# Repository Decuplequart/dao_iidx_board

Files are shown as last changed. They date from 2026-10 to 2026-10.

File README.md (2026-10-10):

# DAO Controller Board

DAO系IIDXコントローラーの既存ボタン、ターンテーブルセンサー、LEDハーネスを再利用し、USB HIDおよびBluetooth Low Energy HIDへの対応を目指す交換用コントローラー基板です。

本リポジトリには、KiCadで作成した回路図・PCBデータ、プロジェクト固有ライブラリ、およびJLCPCB向け製造データ生成に必要な設定を収録します。

Repository: https://github.com/Decuplequart/dao_iidx_board

> [!WARNING]
> この基板は現在 **Rev.1の試作段階** です。実機での完全な動作確認、長時間運転、全LED同時点灯時の温度評価、USB/BLEファームウェア検証は完了していません。製造・実装・使用は自己責任で行ってください。

## 主な機能

- 7鍵入力
- START / SELECT入力
- 2相ターンテーブルセンサー入力（RD1 / RD2）
- USB 2.0 Full-Speed HID対応を想定
- Bluetooth Low Energy HID対応を想定
- DAO系単色ボタンLED 9系統の個別制御
- RESETボタン
- MODE / PAIRボタン
- SWD書き込み端子
- 8 GPIOの拡張端子
- USB Type-C給電
- モバイルバッテリー給電によるBLE運用を想定

## 設計方針

この基板は内蔵バッテリーを搭載せず、USB Type-Cからの5V給電に統一しています。

- 有線使用時: PCとのUSB通信および給電
- 無線使用時: BLE通信および外部モバイルバッテリーからの給電

内蔵LiPo、充電回路、昇圧回路を省略することで、回路の簡略化、安全性の向上、保守性の改善を狙っています。

## ハードウェア構成

### マイコン

- Raytac `MDBT50Q-1MV2`
- Nordic Semiconductor `nRF52840`搭載
- USB / BLE対応
- チップアンテナ内蔵
- SWD経由で初回書き込み可能

JLCPCB/LCSC部品番号:

```text
C5118826
```

この部品は通常在庫ではなく、事前注文が必要になる場合があります。また、ブートローダーやアプリケーションが未書き込みの可能性があるため、SWD書き込みを前提としてください。

### LEDドライバ

- Texas Instruments `TLC6C598PWR` × 2
- 8ch DMOSオープンドレイン出力
- 2個をカスケード接続し、9系統を使用

DAO系単色ボタンLEDの実測電流は1灯あたり約40～50mAでした。LED電源は5V、ドライバ出力はローサイドシンク方式です。

```text
U2 DRAIN0～7 -> LED_K1～LED_K8
U3 DRAIN0    -> LED_K9
```

### 電源

```text
USB Type-C VBUS
  -> VBUS_5V
     -> MDBT50Q VDDH / VBUS
     -> TLC6C598 × 2
     -> KEY_LED_5V
     -> SCR_5V
     -> DISH_LED_5V
```

- 内蔵バッテリーなし
- USB Type-C受電用CC抵抗: 5.1kΩ × 2
- キーLED共通電源は太配線で分配
- 裏面GNDゾーンを使用

## GPIO割り当て

| 機能 | nRF52840 GPIO |
|---|---|
| K1 | P0.02 |
| K2 | P0.03 |
| K3 | P0.04 |
| K4 | P0.05 |
| K5 | P0.28 |
| K6 | P0.29 |
| K7 | P0.30 |
| START | P0.00 |
| SELECT | P0.01 |
| MODE_PAIR | P0.06 |
| RD1 | P0.13 |
| RD2 | P0.14 |
| LED_DATA | P0.15 |
| LED_CLK | P0.16 |
| LED_LATCH | P0.17 |
| RESET | P0.18 / nRESET |

### 拡張GPIO

`GPIO_EXPANSION`端子へ次の8本を引き出しています。

```text
EXP0 -> P0.19
EXP1 -> P0.20
EXP2 -> P0.21
EXP3 -> P0.22
EXP4 -> P0.23
EXP5 -> P0.24
EXP6 -> P0.25
EXP7 -> P0.26
```

将来のPS2対応や追加I/Oへの利用を想定していますが、現時点では用途・ファームウェアとも未確定です。

## コネクター

| 機能 | 種類 |
|---|---|
| DISH_LED | JST XH 2極、2.50mm、垂直 |
| KEY1～KEY7 | JST XH 4極、2.50mm、垂直 |
| START / SELECT | JST XH 4極、2.50mm、垂直 |
| DISH_SENSOR | JST XH 4極、2.50mm、垂直 |
| SWD | 1×4、2.54mmピンヘッダー |
| GPIO_EXPANSION | 2×5、2.54mmピンヘッダー |

キー・START・SELECT用4極コネクターの基本構成:

```text
Pin 1: スイッチ入力
Pin 2: LED制御端子（LOWで点灯）
Pin 3: KEY_LED_5V
Pin 4: GND
```

実際の既存ハーネスを接続する前に、必ず導通とピン順を確認してください。

## SWD端子

```text
J3 Pin 1: +3V3 / VTref
J3 Pin 2: SWDIO
J3 Pin 3: SWDCLK
J3 Pin 4: GND
```

J-Link、nRF52840 DK、またはJLCPCBのプログラミングサービスを使った初回書き込みを想定しています。

## 基板仕様

```text
基板外形: 80.00 mm × 57.00 mm
層数: 2層
推奨板厚: 1.6 mm
銅厚: 1 oz
固定穴: 4個、5.5 mm NPTH
```

固定穴中心位置は、基板左上を `(0, 0)` とした場合、次のとおりです。

```text
左上: ( 4.5, 15.0 ) mm
右上: (75.5, 15.0 ) mm
左下: ( 4.5, 45.0 ) mm
右下: (75.5, 45.0 ) mm
```

## アンテナ領域の注意

`MDBT50Q-1MV2`のアンテナKEEP OUT内には、表裏とも次を配置しないでください。

- 銅箔ゾーン
- 配線
- ビア
- 部品
- 金属スペーサー
- ネジや金属板

Gerber出力後、アンテナ領域からGNDベタが正しく抜けていることを必ず確認してください。

## 主なJLCPCB/LCSC部品

| リファレンス | 部品 | LCSC番号 |
|---|---|---|
| C1, C3, C4, C6 | 100nF / 16V / 0402 | C1525 |
| C2, C5 | 4.7uF / 16V / 0603 | C19666 |
| D1 | 1SS404 / SOD-323 | C2847422 |
| D2 | SS14 / SMA | C2480 |
| R1 | 0Ω / 0402 | C17168 |
| R2, R3 | 5.1kΩ / 0402 | C25905 |
| R4, R5 | 10kΩ / 0402 | C25744 |
| R6, R7 | 1kΩ / 0402 | C11702 |
| SW1, SW2 | SMDタクトスイッチ | C49234124 |
| U1 | MDBT50Q-1MV2 | C5118826 |
| U2, U3 | TLC6C598PWR | C2863406 |
| USB-C | TYPE-C-31-M-12 | C165948 |
| J1 | JST B2B-XH-A | C158012 |
| J3 | 1×4 2.54mmピンヘッダー | C5116483 |
| J4 | 2×5 2.54mmピンヘッダー | C492422 |
| J5～J14 | JST B4B-XH-A | C144395 |

> [!NOTE]
> 在庫、価格、Basic/Extended区分、Standard PCBA対応状況は変動します。発注直前にJLCPCBの部品ページと実装プレビューで再確認してください。

## リポジトリ構成

```text
.
├─ *.kicad_pro              KiCadプロジェクト
├─ *.kicad_sch              回路図
├─ *.kicad_pcb              PCB
├─ *.kicad_sym              プロジェクト固有シンボル
├─ *.pretty/                プロジェクト固有フットプリント
├─ *.3dshapes/              3Dモデル
├─ fp-lib-table             フットプリントライブラリ設定
├─ sym-lib-table            シンボルライブラリ設定
└─ README.md
```

3Dモデルは製造そのものには必須ではありません。Gerber、ドリル、BOM、CPLの内容を優先してください。

## 製造データの生成

KiCad用`JLCPCB Tools`プラグインを使用する場合:

1. PCBエディターでDRCを実行
2. エラー0、未配線0を確認
3. GNDゾーンを再計算
4. JLCPCB Toolsを開く
5. 各実装部品へLCSC番号を割り当て
6. 固定穴とテストポイントをBOM/POSから除外
7. `Generate`を実行

PCBA発注に必要な主なファイル:

```text
Gerber + Drill ZIP
BOM.csv
CPL / Positions.csv
```

発注時はJLCPCBのプレビューで、少なくとも次を確認してください。

- U1、U2、U3の1番ピン方向
- D1、D2のカソード方向
- USB Type-Cの向き
- JST-XHコネクターの向き
- タクトスイッチの位置
- SMT部品の回転角
- PTH/NPTH穴
- アンテナKEEP OUT
- 表裏シルク

## ファームウェア

ファームウェアは別途開発予定です。

想定機能:

- USB HIDゲームコントローラー
- BLE HIDゲームコントローラー
- 7鍵、START、SELECT入力
- ターンテーブル2相入力
- LED制御
- MODE / PAIR操作
- 将来の拡張GPIO利用

初回書き込みはSWDを使用します。JLCPCBへ書き込みを依頼する場合は、対象デバイス、SWD端子定義、書き込み対象HEX、Erase/Program/Verify手順を明記してください。

## 既知の注意事項

- Rev.1は未検証です。
- DAO系コントローラーの世代やモデルにより、ハーネスのピン配列が異なる可能性があります。
- LED電流は実機で約40～50mA/灯を観測しています。
- 9灯同時点灯時はLEDだけで約360～450mAになる可能性があります。
- モバイルバッテリーによっては低負荷時に自動停止する場合があります。
- U1は事前注文、Standard PCBA、X線検査が必要になる場合があります。
- U1が未書き込み品の場合、SWD経由の初回書き込みが必要です。
- 未確認の状態でPC、コントローラー、既存ハーネスへ接続しないでください。

## ライセンス

本リポジトリの内容は、特に明記がない限り **MIT License** の下で公開します。

詳細は[`LICENSE`](LICENSE)を参照してください。

## Disclaimer

本プロジェクトは非公式の個人製作物です。DAO、JLCPCB、LCSC、Raytac、Nordic Semiconductor、Texas Instruments、JSTその他の各社とは関係ありません。各名称および商標は、それぞれの権利者に帰属します。

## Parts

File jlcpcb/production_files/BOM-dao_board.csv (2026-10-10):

Comment | Designator | Footprint | LCSC | Quantity
0 | R1 | R_0402_1005Metric | C17168 | 1
100n | C1,C3,C4,C6 | C_0402_1005Metric | C1525 | 4
10k | R4,R5 | R_0402_1005Metric | C25744 | 2
1SS404 | D1 | D_SOD-323 | C2847422 | 1
1k | R6,R7 | R_0402_1005Metric | C11702 | 2
4.7u | C2,C5 | C_0603_1608Metric | C19666 | 2
5.1k | R2,R3 | R_0402_1005Metric | C25905 | 2
DISH_LED | J1 | JST_XH_B2B-XH-A_1x02_P2.50mm_Vertical | C158012 | 1
DISH_SENSOR | J14 | JST_XH_B4B-XH-A_1x04_P2.50mm_Vertical | C144395 | 1
GPIO_EXPANSION | J4 | PinHeader_2x05_P2.54mm_Vertical | C492422 | 1
HX 3x4x2-2P-1.6N | SW2 | KEY-SMD_L4.0-W3.0-LS4.9-1 | C49234124 | 1
KEY1 | J5 | JST_XH_B4B-XH-A_1x04_P2.50mm_Vertical | C144395 | 1
KEY2 | J6 | JST_XH_B4B-XH-A_1x04_P2.50mm_Vertical | C144395 | 1
KEY3 | J7 | JST_XH_B4B-XH-A_1x04_P2.50mm_Vertical | C144395 | 1
KEY4 | J8 | JST_XH_B4B-XH-A_1x04_P2.50mm_Vertical | C144395 | 1
KEY5 | J9 | JST_XH_B4B-XH-A_1x04_P2.50mm_Vertical | C144395 | 1
KEY6 | J10 | JST_XH_B4B-XH-A_1x04_P2.50mm_Vertical | C144395 | 1
KEY7 | J11 | JST_XH_B4B-XH-A_1x04_P2.50mm_Vertical | C144395 | 1
MDBT50Q-1MV2 | U1 | Raytac_MDBT50Q | C5118826 | 1
RESET | SW1 | KEY-SMD_L4.0-W3.0-LS4.9-1 | C49234124 | 1
SELECT | J13 | JST_XH_B4B-XH-A_1x04_P2.50mm_Vertical | C144395 | 1
SS14 | D2 | D_SMA | C2480 | 1
START | J12 | JST_XH_B4B-XH-A_1x04_P2.50mm_Vertical | C144395 | 1
SWD | J3 | FanPinHeader_1x04_P2.54mm_Vertical | C5116483 | 1
TLC6C598PWR | U2,U3 | TSSOP-16_L5.0-W4.4-P0.65-LS6.4-BL | C2863406 | 2
TYPE-C-31-M-12 | USBC1 | USB-C_SMD-TYPE-C-31-M-12_1 | C165948 | 1

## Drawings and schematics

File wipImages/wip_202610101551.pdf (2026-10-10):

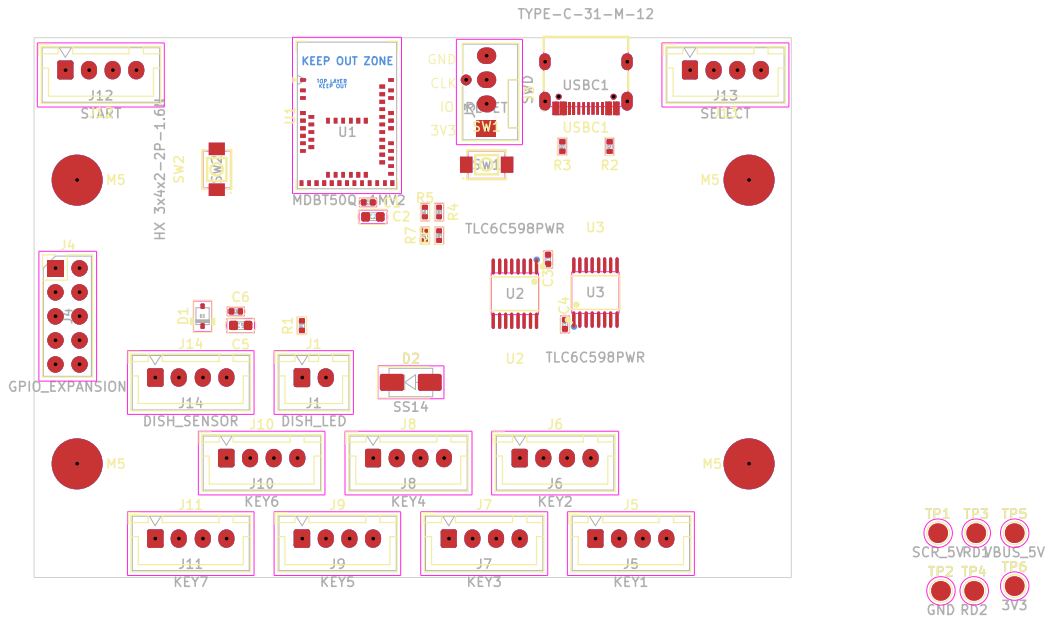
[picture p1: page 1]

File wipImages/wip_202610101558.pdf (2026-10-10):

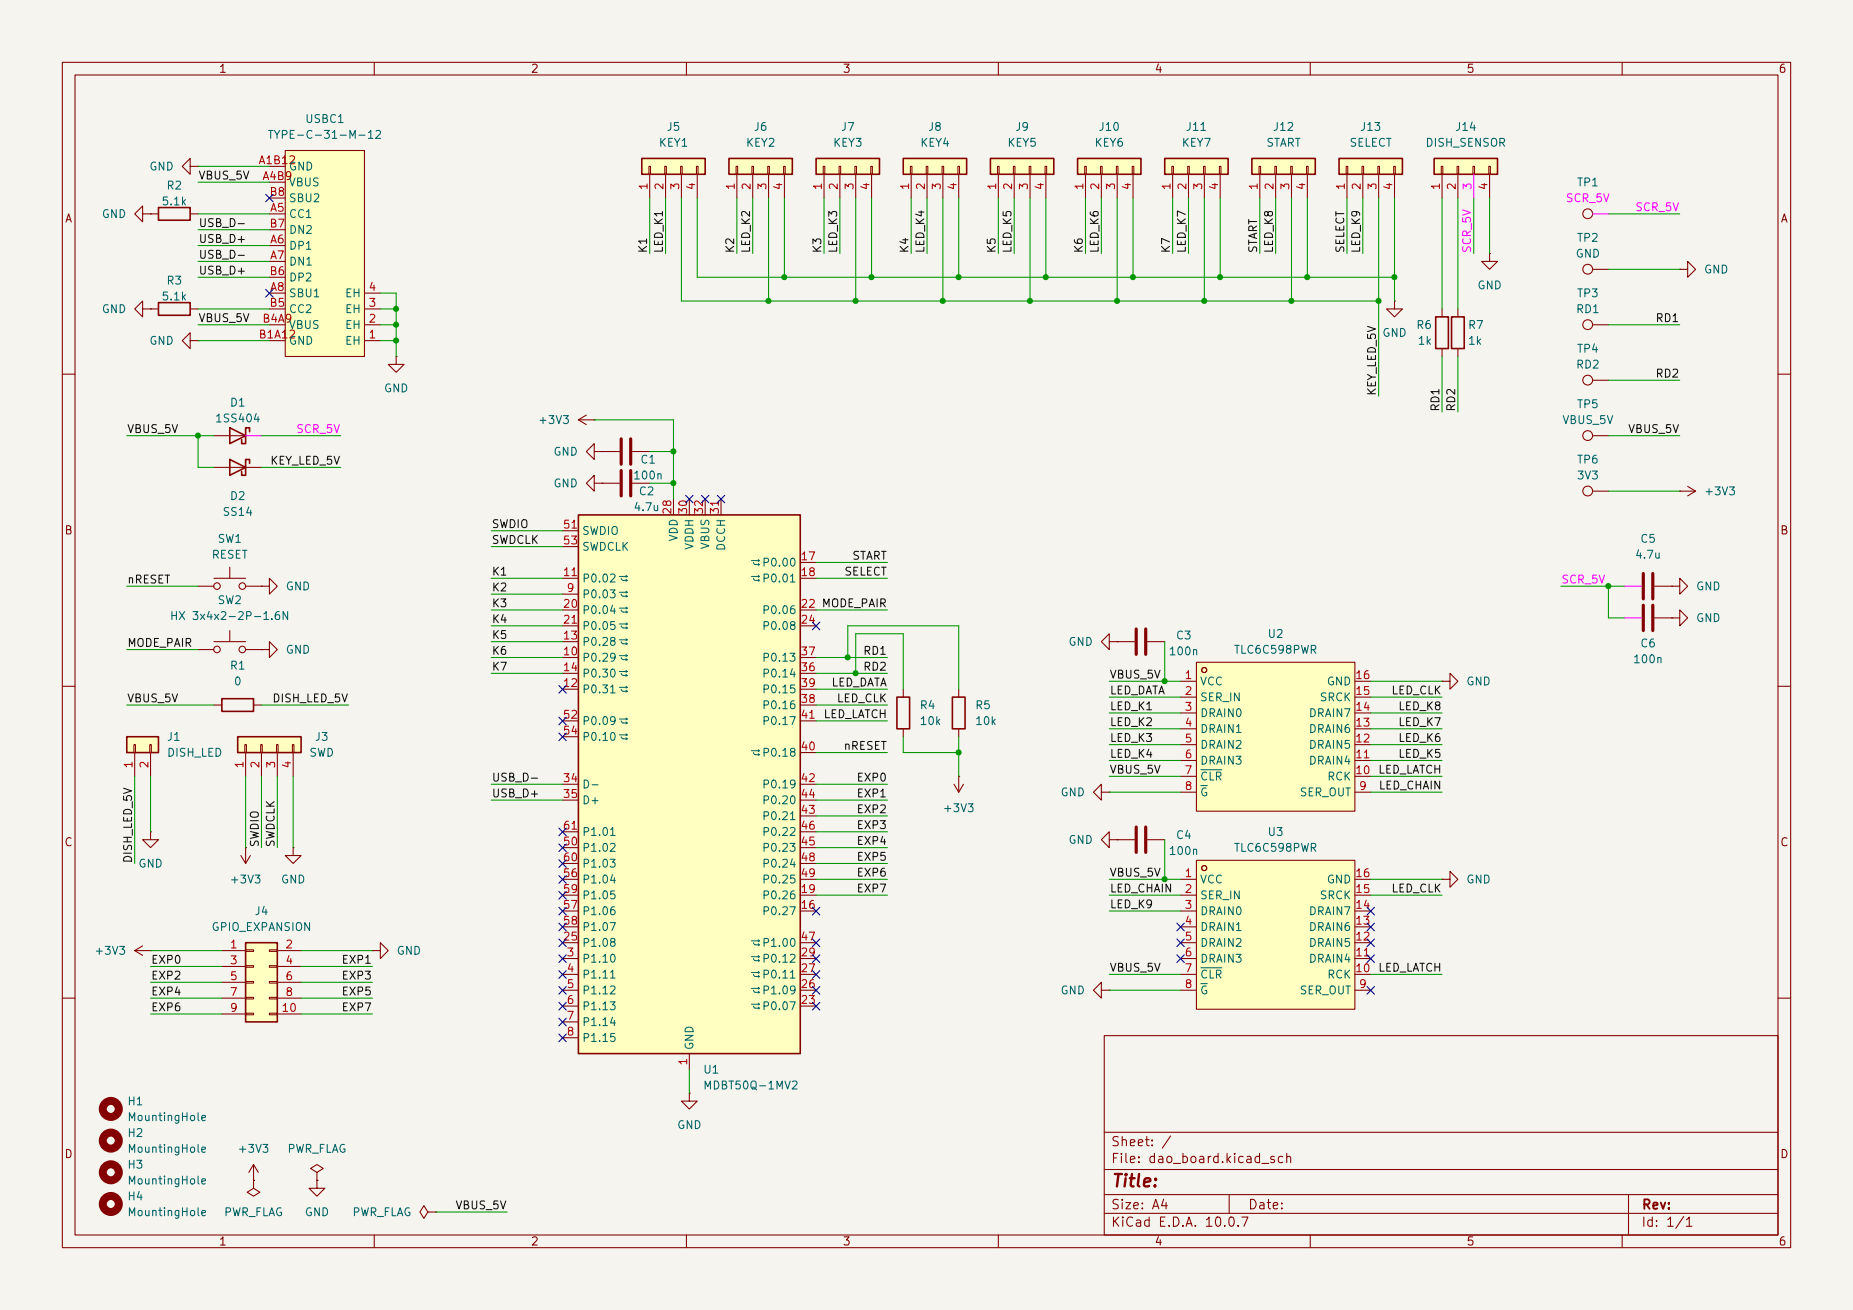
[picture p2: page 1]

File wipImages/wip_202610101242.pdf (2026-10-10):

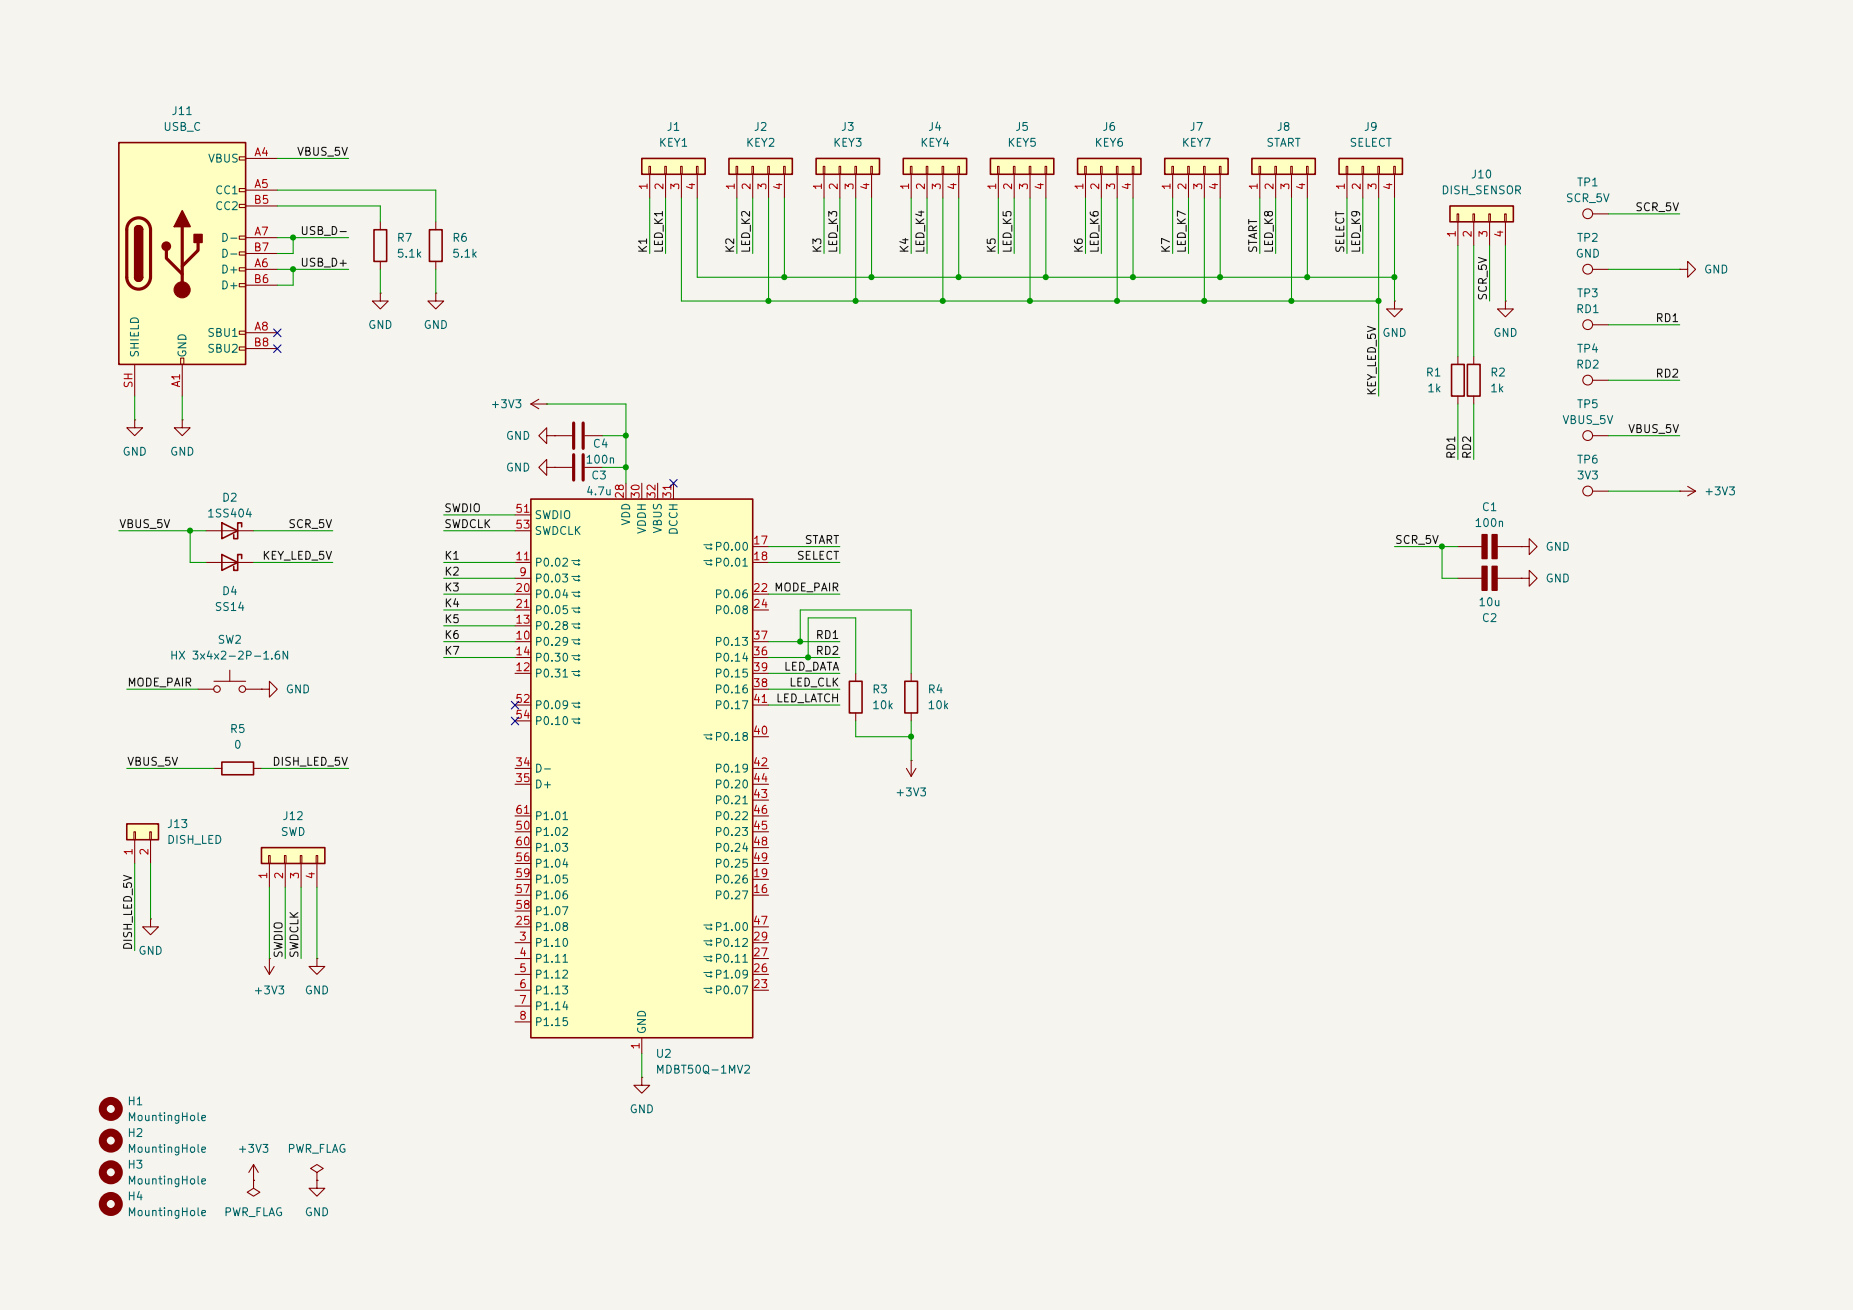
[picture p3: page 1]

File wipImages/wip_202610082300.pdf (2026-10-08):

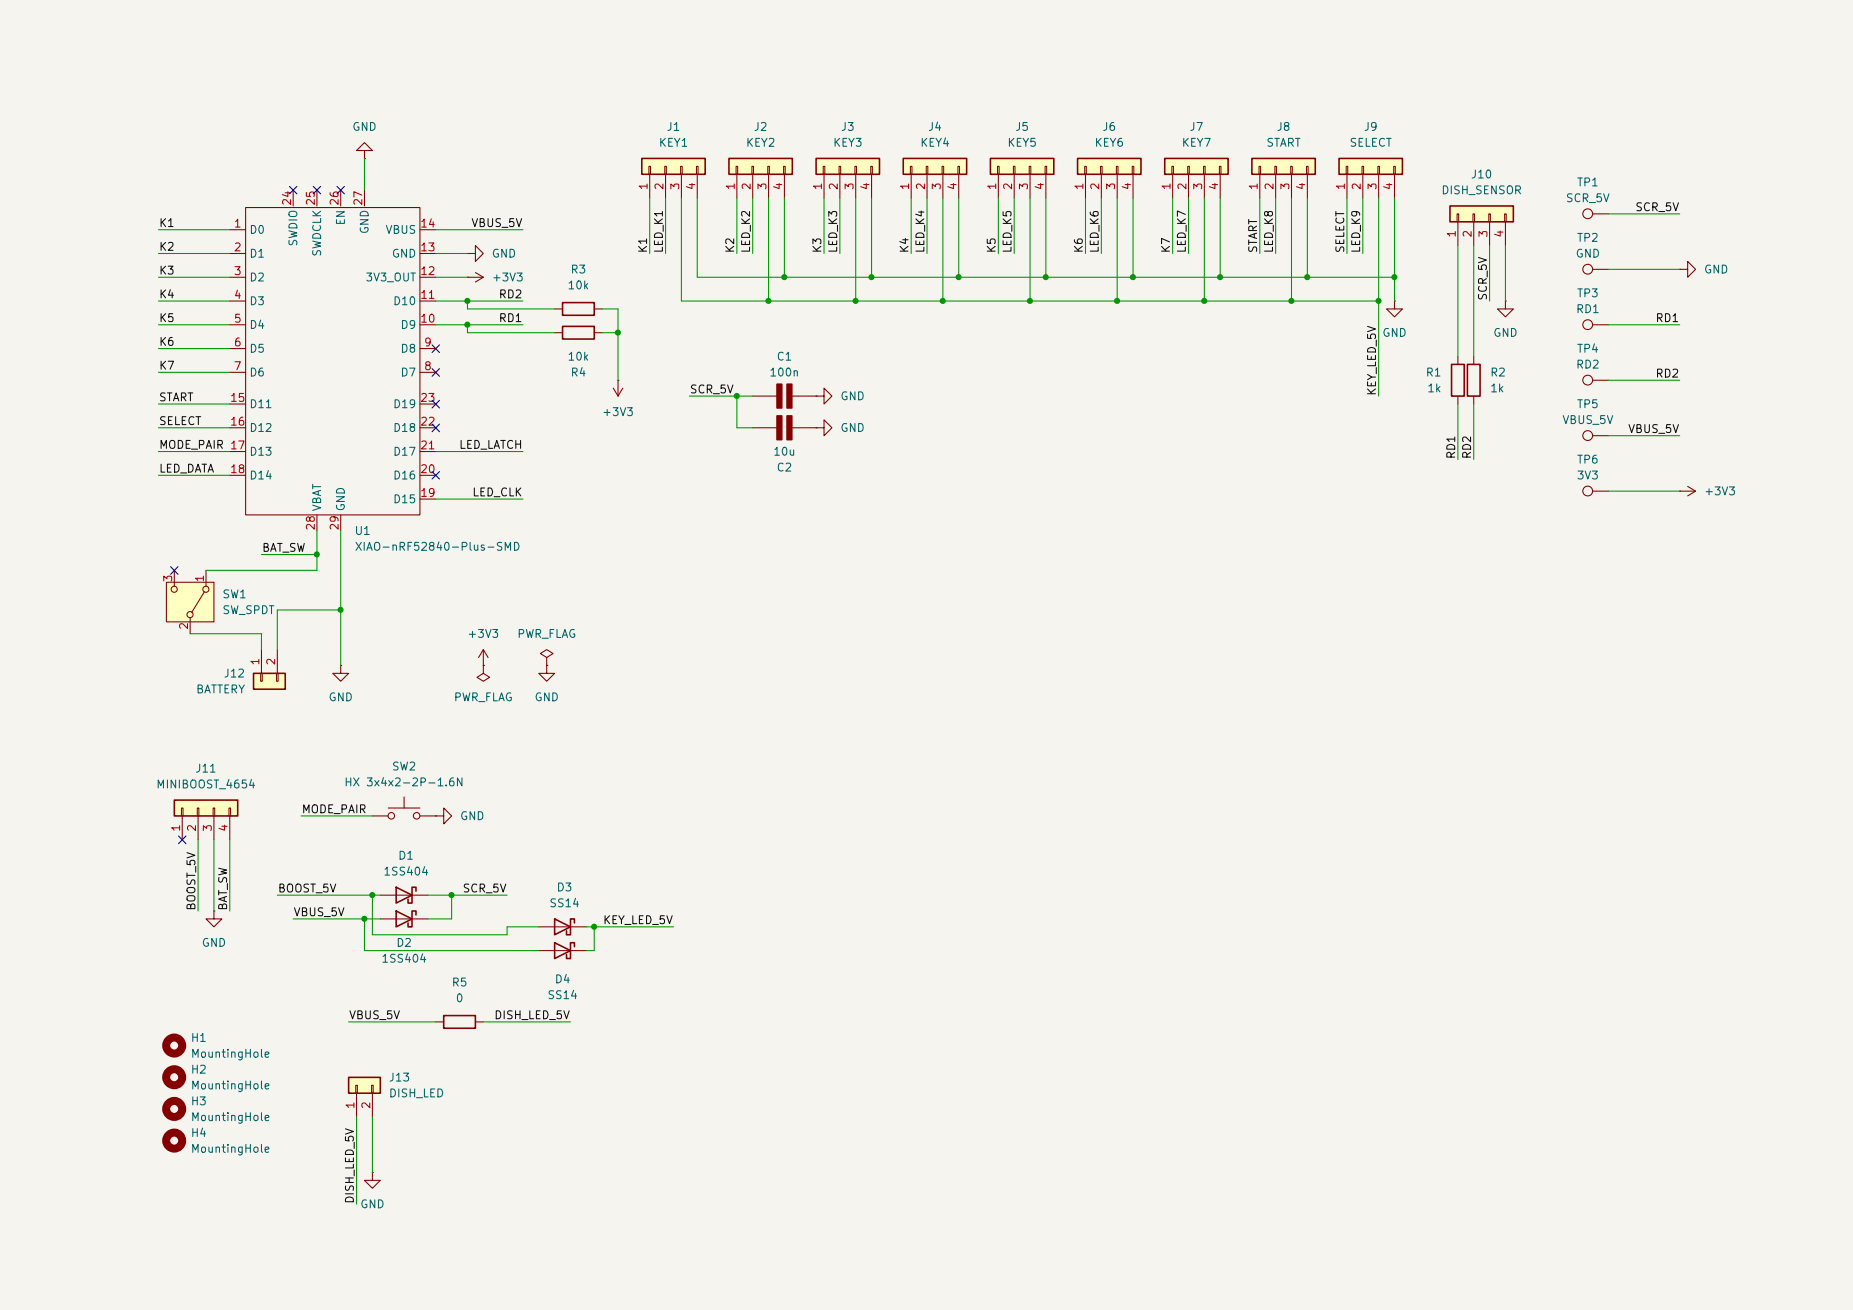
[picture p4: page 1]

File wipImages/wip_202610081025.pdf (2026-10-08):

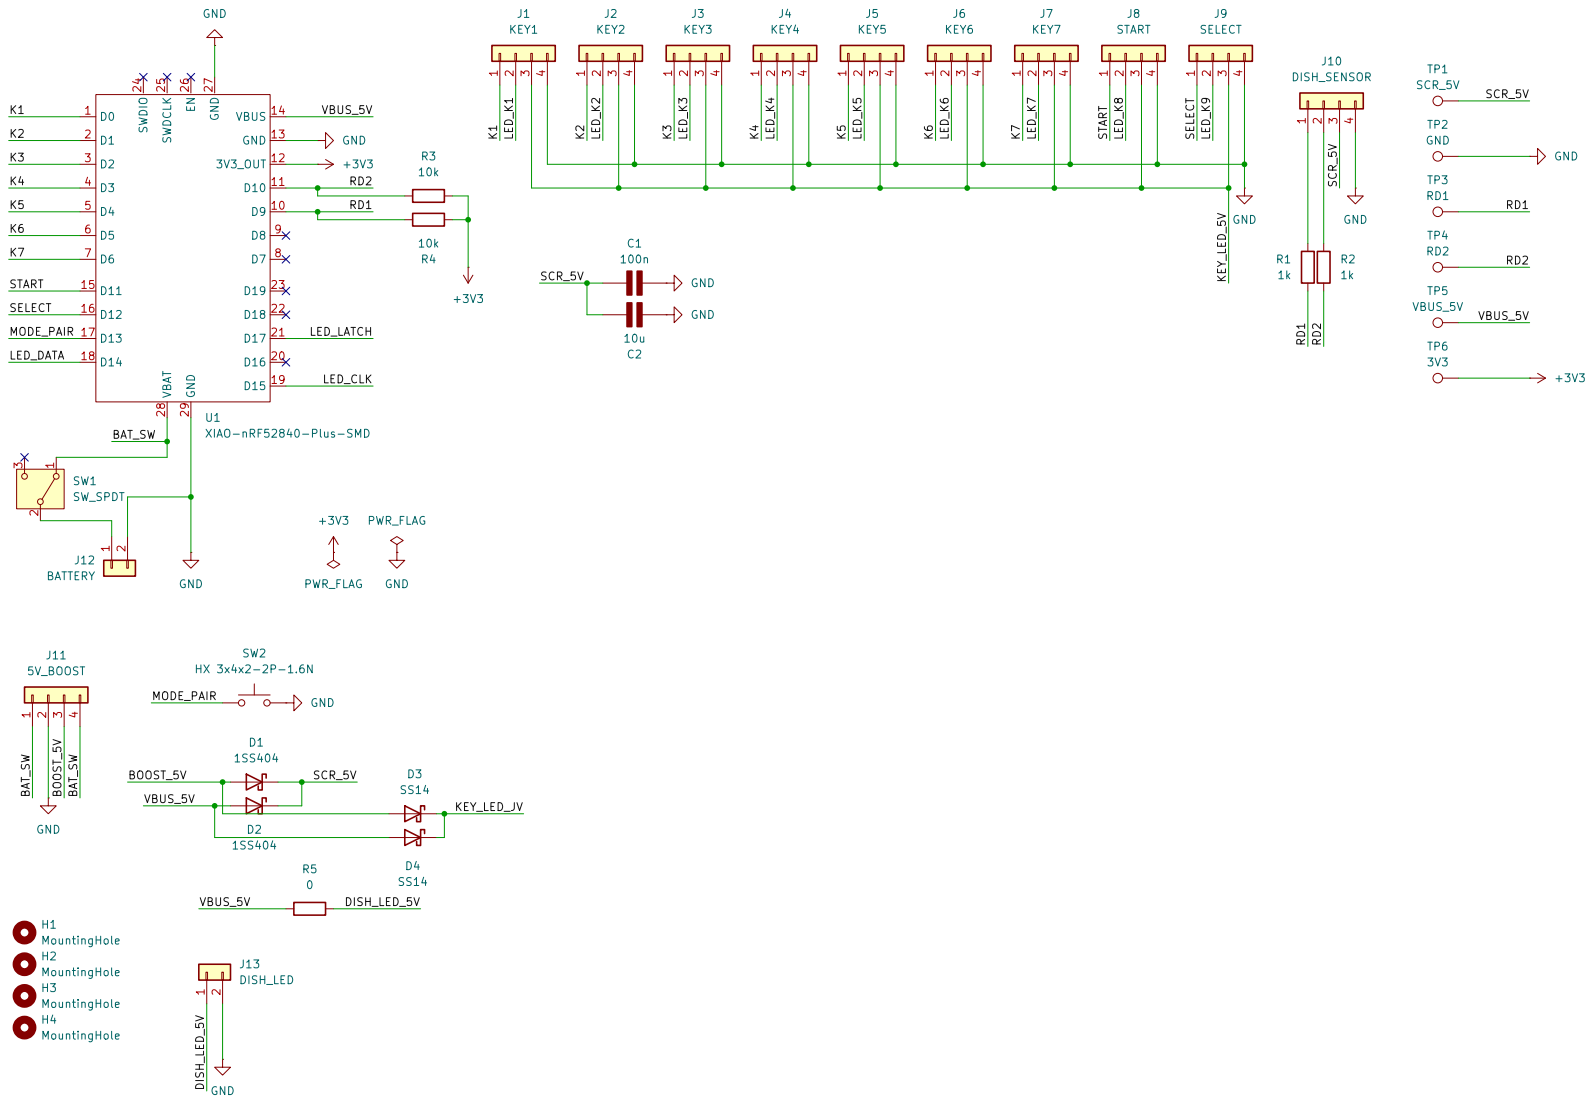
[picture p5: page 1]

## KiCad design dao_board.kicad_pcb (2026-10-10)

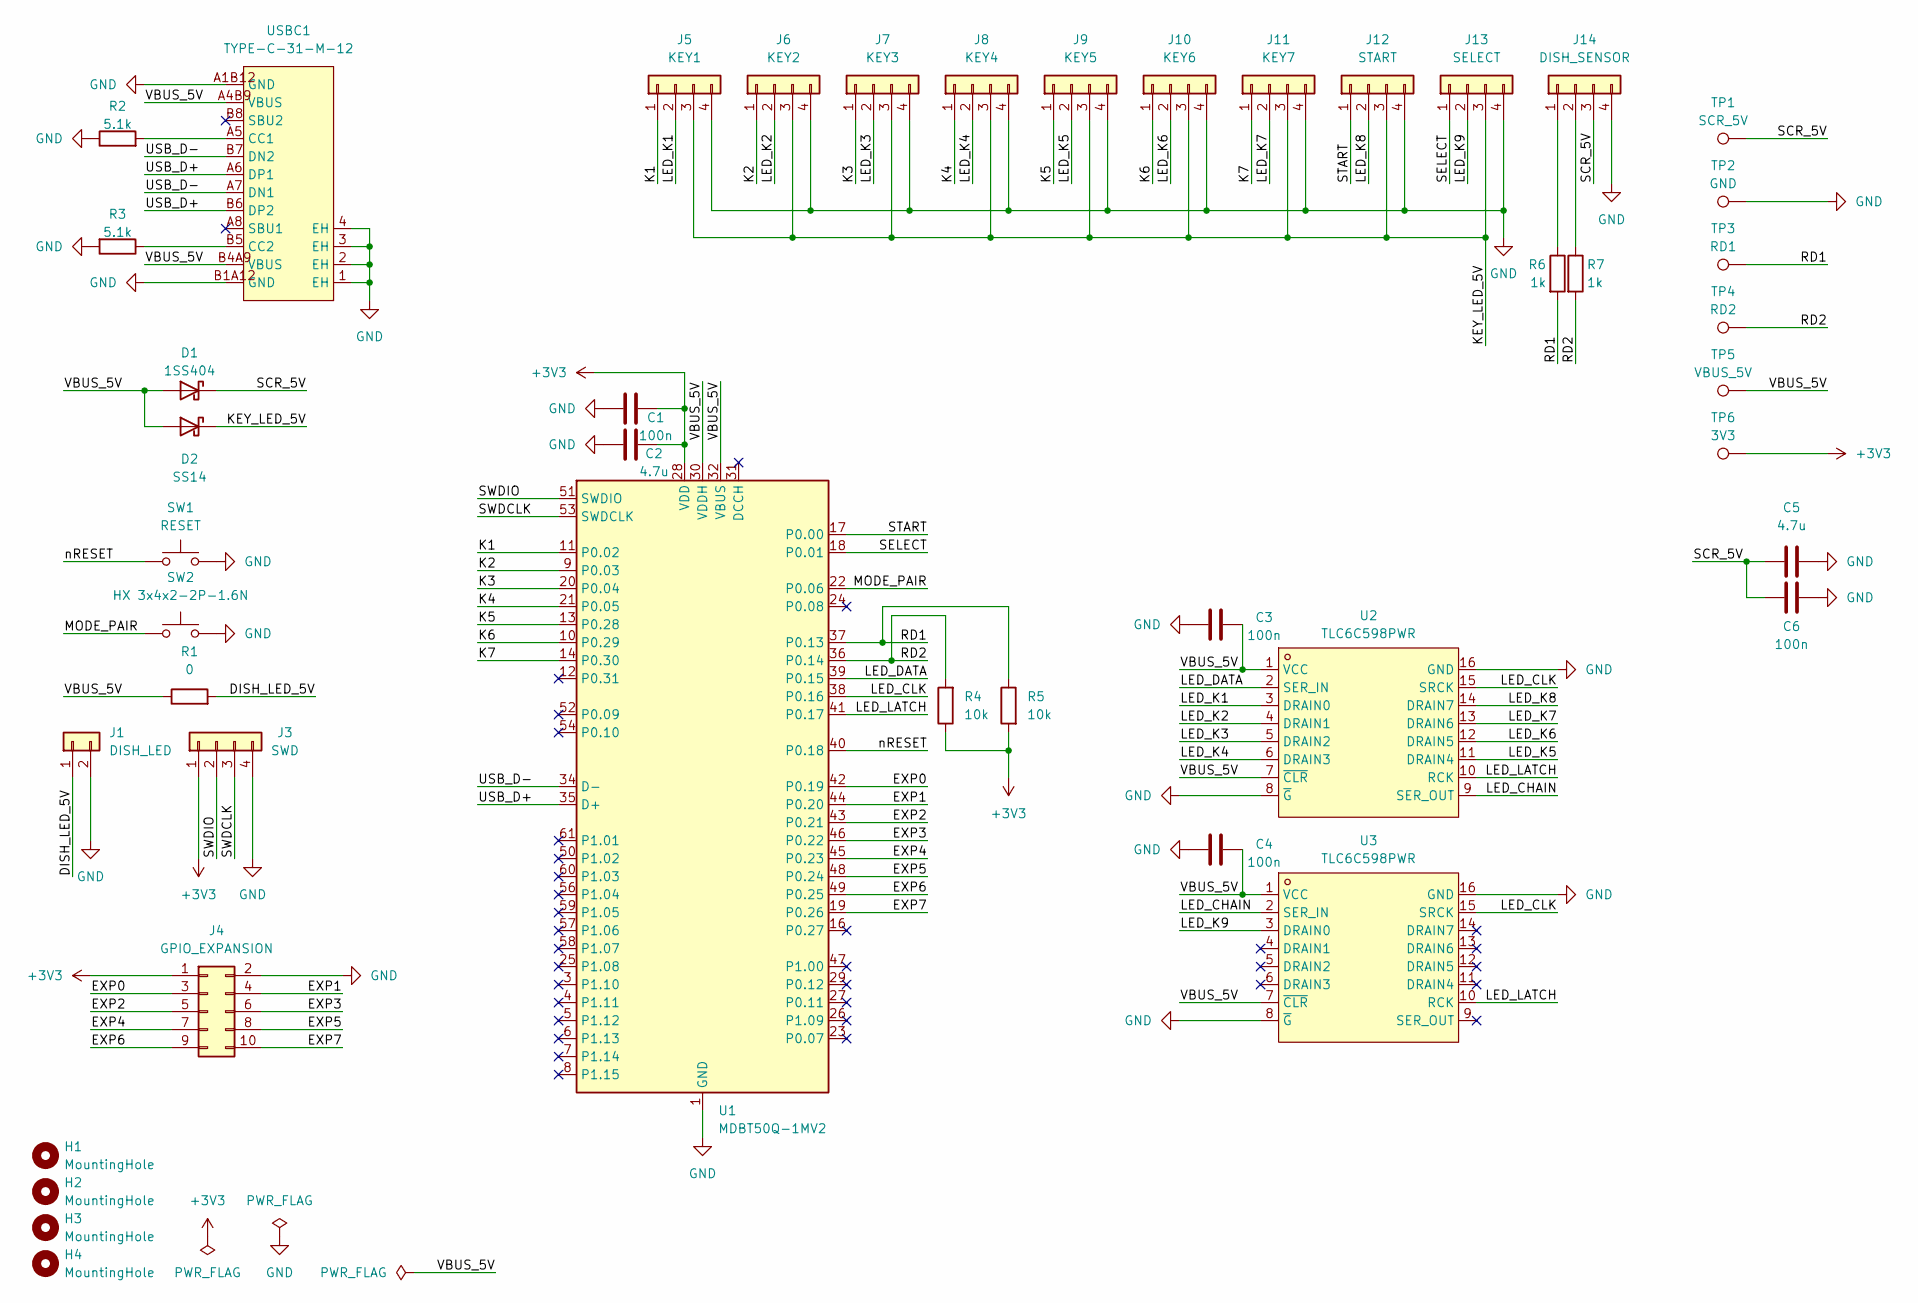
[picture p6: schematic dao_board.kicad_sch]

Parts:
C1, C3, C4, C6: 100n; C_0402_1005Metric
C2, C5: 4.7u; C_0603_1608Metric
D1: 1SS404; D_SOD-323
D2: SS14; D_SMA
H1, H2, H3, H4: MountingHole; MountingHole_M5
J1: DISH_LED; JST_XH_B2B-XH-A_1x02_P2.50mm_Vertical
J3: SWD; FanPinHeader_1x04_P2.54mm_Vertical
J4: GPIO_EXPANSION; PinHeader_2x05_P2.54mm_Vertical
J5: KEY1; JST_XH_B4B-XH-A_1x04_P2.50mm_Vertical
J6: KEY2; JST_XH_B4B-XH-A_1x04_P2.50mm_Vertical
J7: KEY3; JST_XH_B4B-XH-A_1x04_P2.50mm_Vertical
J8: KEY4; JST_XH_B4B-XH-A_1x04_P2.50mm_Vertical
J9: KEY5; JST_XH_B4B-XH-A_1x04_P2.50mm_Vertical
J10: KEY6; JST_XH_B4B-XH-A_1x04_P2.50mm_Vertical
J11: KEY7; JST_XH_B4B-XH-A_1x04_P2.50mm_Vertical
J12: START; JST_XH_B4B-XH-A_1x04_P2.50mm_Vertical
J13: SELECT; JST_XH_B4B-XH-A_1x04_P2.50mm_Vertical
J14: DISH_SENSOR; JST_XH_B4B-XH-A_1x04_P2.50mm_Vertical
R1: 0; R_0402_1005Metric
R2, R3: 5.1k; R_0402_1005Metric
R4, R5: 10k; R_0402_1005Metric
R6, R7: 1k; R_0402_1005Metric
SW1: RESET; KEY-SMD_L4.0-W3.0-LS4.9-1
SW2: HX 3x4x2-2P-1.6N; KEY-SMD_L4.0-W3.0-LS4.9-1
TP1: SCR_5V; TestPoint_Pad_D2.0mm
TP2: GND; TestPoint_Pad_D2.0mm
TP3: RD1; TestPoint_Pad_D2.0mm
TP4: RD2; TestPoint_Pad_D2.0mm
TP5: VBUS_5V; TestPoint_Pad_D2.0mm
TP6: 3V3; TestPoint_Pad_D2.0mm
U1: MDBT50Q-1MV2; Raytac_MDBT50Q_FIXED; LCSC Part C5118826
U2, U3: TLC6C598PWR; TSSOP-16_L5.0-W4.4-P0.65-LS6.4-BL; MPN TLC6C598PWR; LCSC Part C2863406
USBC1: TYPE-C-31-M-12; USB-C_SMD-TYPE-C-31-M-12_1_FIXED; MPN TYPE-C-31-M-12; LCSC Part C165948

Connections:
+3V3: C1.2, C2.2, J3.1, J4.1, R4.1, R5.2, TP6.1 (1_1), U1.28 (VDD)
/DISH_LED_5V: J1.1, R1.2
/EXP0: J4.3, U1.42 (P0.19)
/EXP1: J4.4, U1.44 (P0.20)
/EXP2: J4.5, U1.43 (P0.21)
/EXP3: J4.6, U1.46 (P0.22)
/EXP4: J4.7, U1.45 (P0.23)
/EXP5: J4.8, U1.48 (P0.24)
/EXP6: J4.9, U1.49 (P0.25)
/EXP7: J4.10, U1.19 (P0.26)
/K1: J5.1, U1.11 (P0.02)
/K2: J6.1, U1.9 (P0.03)
/K3: J7.1, U1.20 (P0.04)
/K4: J8.1, U1.21 (P0.05)
/K5: J9.1, U1.13 (P0.28)
/K6: J10.1, U1.10 (P0.29)
/K7: J11.1, U1.14 (P0.30)
/KEY_LED_5V: D2.1 (K), J5.3, J6.3, J7.3, J8.3, J9.3, J10.3, J11.3, J12.3, J13.3
/LED_CHAIN: U2.9 (SER_OUT), U3.2 (SER_IN)
/LED_CLK: U1.38 (P0.16), U2.15 (SRCK), U3.15 (SRCK)
/LED_DATA: U1.39 (P0.15), U2.2 (SER_IN)
/LED_K1: J5.2, U2.3 (DRAIN0)
/LED_K2: J6.2, U2.4 (DRAIN1)
/LED_K3: J7.2, U2.5 (DRAIN2)
/LED_K4: J8.2, U2.6 (DRAIN3)
/LED_K5: J9.2, U2.11 (DRAIN4)
/LED_K6: J10.2, U2.12 (DRAIN5)
/LED_K7: J11.2, U2.13 (DRAIN6)
/LED_K8: J12.2, U2.14 (DRAIN7)
/LED_K9: J13.2, U3.3 (DRAIN0)
/LED_LATCH: U1.41 (P0.17), U2.10 (RCK), U3.10 (RCK)
/MODE_PAIR: SW2.1, U1.22 (P0.06)
/RD1: R5.1, R6.2, TP3.1 (1_1), U1.37 (P0.13)
/RD2: R4.2, R7.2, TP4.1 (1_1), U1.36 (P0.14)
/SCR_5V: C5.1, C6.1, D1.1 (K), J14.3, TP1.1 (1_1)
/SELECT: J13.1, U1.18 (P0.01)
/START: J12.1, U1.17 (P0.00)
/SWDCLK: J3.3, U1.53 (SWDCLK)
/SWDIO: J3.2, U1.51 (SWDIO)
/USB_D+: U1.35 (D+), USBC1.A6 (DP1), USBC1.B6 (DP2)
/USB_D-: U1.34 (D-), USBC1.A7 (DN1), USBC1.B7 (DN2)
/VBUS_5V: C3.2, C4.2, D1.2 (A), D2.2 (A), R1.1, TP5.1 (1_1), U1.30 (VDDH), U1.32 (VBUS), U2.1 (VCC), U2.7 (~CLR), U3.1 (VCC), U3.7 (~CLR), USBC1.A4B9 (VBUS), USBC1.B4A9 (VBUS)
/nRESET: SW1.1, U1.40 (P0.18)
GND: C1.1, C2.1, C3.1, C4.1, C5.2, C6.2, J1.2, J3.4, J4.2, J5.4, J6.4, J7.4, J8.4, J9.4, J10.4, J11.4, J12.4, J13.4, J14.4, R2.1, R3.2, SW1.2, SW2.2, TP2.1 (1_1), U1.1 (GND), U1.2 (GND), U1.15 (GND), U1.33 (GND), U1.55 (GND), U2.8 (~G), U2.16 (GND), U3.8 (~G), U3.16 (GND), USBC1.1 (EH), USBC1.2 (EH), USBC1.3 (EH), USBC1.4 (EH), USBC1.A1B12 (GND), USBC1.B1A12 (GND)
unnamed: J14.1, R6.1
unnamed: J14.2, R7.1
unnamed: R2.2, USBC1.A5 (CC1)
unnamed: R3.1, USBC1.B5 (CC2)

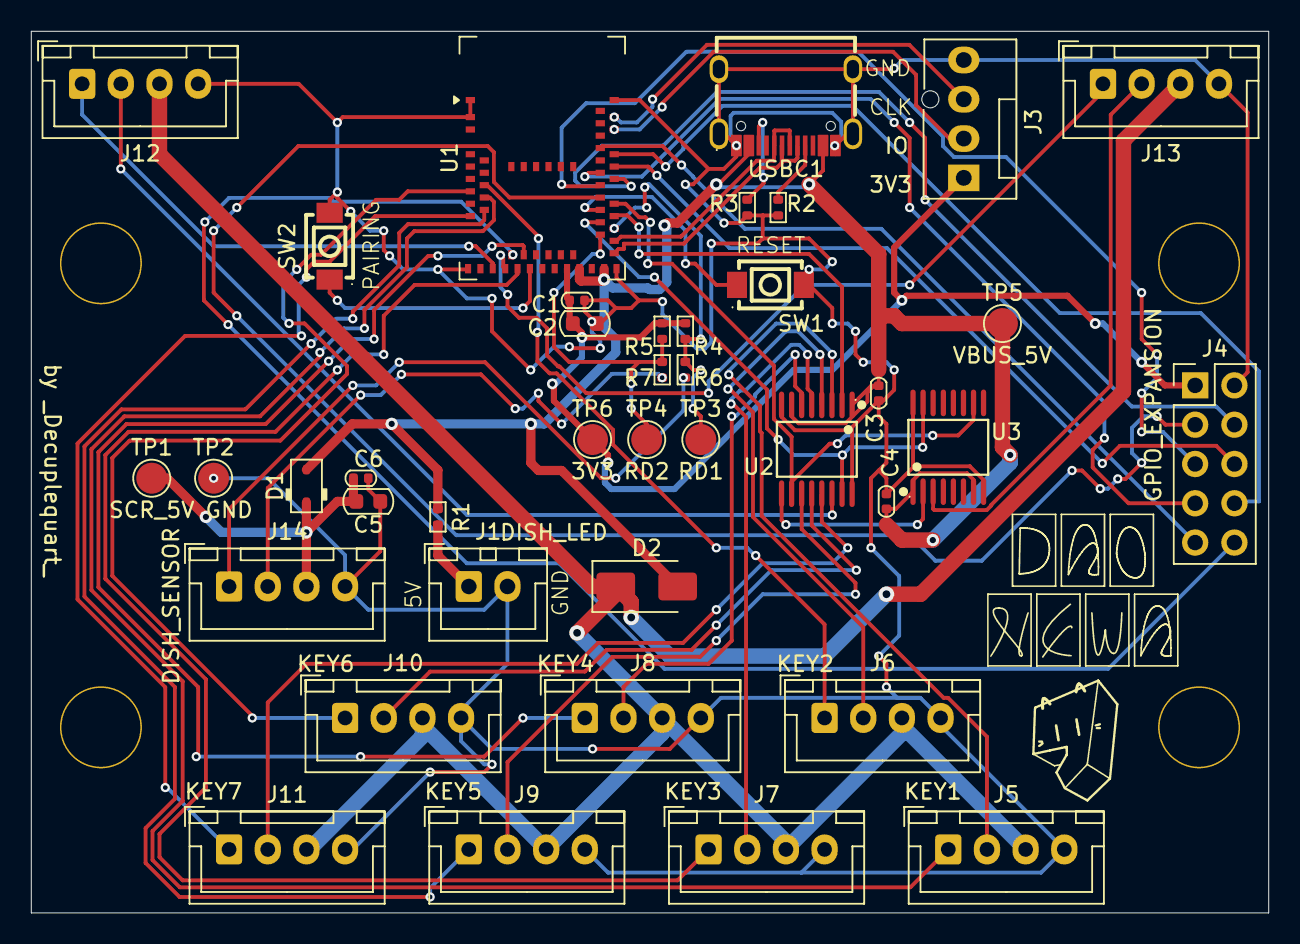
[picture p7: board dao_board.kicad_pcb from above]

Board: 2 copper layers, 80.0 x 57.0 mm, 44 parts (0 on the bottom side), 48 nets.

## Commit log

2026-10-07 りどみのちょっとした修正
2026-10-08 ネット名ミスってて直すなど
    [dao_board.kicad_sch]
2026-10-08 .gitignoreで.history/を無視
2026-10-08 Ignore KiCad lock files
2026-10-08 .gitignore書き換え(.bak, .bck, .lckなど追加)
2026-10-08 昇圧モジュールをMiniBoostに確定、フットプリントを自作する必要あり(多分ソケットにする)
    [dao_board.kicad_sch]
2026-10-08 回路図を大幅に更新したのでPCBは作り直し
    [dao_board.kicad_pcb]
2026-10-08 フットプリント自作にあたって必要なデータをdata_tempに保存することとした、あとは回路図をモジュールに合わせて変更
    [Adafruit TPS61023.brd, dao_board.kicad_pcb, dao_board.kicad_sch]
2026-10-08 方針変更: BLE接続時でも給電はUSBから取ることにする。PS2は対応できる形にしておくのと、マイコンもGPIOが足りないので変更
    [dao_board.kicad_sch]
2026-10-08 nRF52840 Plusに接続されていたものを1MV2へ移植、USB_Cシンボルの追加など
    [Adafruit TPS61023.brd, dao_board.kicad_sch]
2026-10-08 READMEの方針とかの些細な変更
2026-10-09 ちょっとした変更
2026-10-09 KiCad閉じるときに保存されて内容が書き換わったので整合性を取るためコミット&プッシュ
2026-10-10 配線・フットプリント割り当ての修正、ディレクトリ内に使ったデータを追加、AIに投げるためのERCレポート保存フォルダ追加など
    [dao_board.kicad_sch]
2026-10-10 とりあえずリセットスイッチ用にシンボルを増やした
    [dao_board.kicad_sch]
2026-10-10 余ったピンを未接続としてマーク
    [dao_board.kicad_sch]
2026-10-10 C3, C4コンデンサが何故か古いライブラリ参照してたので標準シンボルに置き換え
    [dao_board.kicad_sch]
2026-10-10 PWR_FLAGが何故か古いライブラリを参照してたので標準シンボルに置き換え
    [dao_board.kicad_sch]
2026-10-10 LEDドライバーの選定、データを引っ張ってきて配置だけした
    [dao_board.kicad_sch]
2026-10-10 LEDドライバーの電源周りだけ配線
    [dao_board.kicad_sch]
2026-10-10 LEDとドライバーの接続、未使用ピンを未接続としてマーク
    [dao_board.kicad_sch]
2026-10-10 LEDとの接続ミスってたので修正、反時計回りになるの毎回忘れるんだが
    [dao_board.kicad_sch]
2026-10-10 一旦の回路図完成、LEDドライバーのシンボルのピンが全て未指定だったので正しく変更した
    [dao_board.kicad_sch]
2026-10-10 README.md進捗更新
2026-10-10 回路図の自動アノテーションのやり直し
    [dao_board.kicad_sch]
2026-10-10 USB_Cのシンボルとフットプリントにxiがあったのでシンボル側を適合させた
    [dao_board.kicad_sch]
2026-10-10 フットプリント割り当て忘れてたので割り当て
    [dao_board.kicad_sch]
2026-10-10 回路図を元にPCBを更新、まだ仮置き
    [dao_board.kicad_pcb]
2026-10-10 USB_Cのピンが未指定になってたのでシンボルを書き直し
    [dao_board.kicad_sch]
2026-10-10 主要部品を配置、ここから位置整理を開始
    [dao_board.kicad_pcb]
2026-10-10 基盤内に部品を収めることに成功、これから配線ルールの設定をする
    [dao_board.kicad_pcb]
2026-10-10 途中まで配線、あとなぜかマイコンにVBUSを接続してなかったので回路図側は修正
    [dao_board.kicad_pcb, dao_board.kicad_sch]
2026-10-10 配線途中のコミット
    [dao_board.kicad_pcb]
2026-10-10 配線スパゲッティ過ぎてこれもうわかんねぇな
    [dao_board.kicad_pcb]
2026-10-10 とりあえず配線は完了(うまく行ってるのかは知らん)
    [dao_board.kicad_pcb, dao_board.kicad_sch]
2026-10-10 一旦基盤は完成とする 配線が終わっているが気にしてはいけない
    [dao_board.kicad_pcb]
2026-10-10 JLCPCB用にデータを用意中
    [dao_board.kicad_pcb, dao_board.kicad_sch]
2026-10-10 ロゴの追加、情報の整理
    [dao_board.kicad_pcb]
2026-10-10 自分のロゴもPCBに入れちゃったり
    [dao_board.kicad_pcb]
2026-10-10 シルクスクリーンを親切にした
    [dao_board.kicad_pcb]
2026-10-10 問題ないとわかっている違反を除外、一応ライブラリを更新したけどなんかうまく行ってないので除外するしか手段がなかった
    [dao_board.kicad_pcb, dao_board.kicad_sch]
2026-10-10 プレースホルダー用シルクスクリーン配置
    [dao_board.kicad_pcb]
2026-10-10 プレースホルダー用シルクスクリーンの線幅を変更
    [dao_board.kicad_pcb]
2026-10-10 製造用ファイルを出力した
    [BOM-dao_board.csv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]
2026-10-10 ERC/DRCレポートフォルダの削除+.gitignoreにrcreportsフォルダを無視することにした
2026-10-10 gitignoreにrcreportsフォルダ追加
2026-10-10 りどみをAIに書かせ、LICENSEを追加(あんまり意味があるかと言われると、無い)
2026-10-11 フォルダ整理なう、PCBデータのフットプリントの参照を変更前のコミット
2026-10-11 シンボル及びフットプリントの参照を整理、とりあえずどのような状況でも開けるようにはなった
2026-10-11 回路図から基板を更新、DRCの完全なクリアに成功
2026-10-11 3dモデルのデータが抜け落ちてたりしたのでひとつのフォルダにまとめた
2026-10-11 製造用データの再出力、だいたいこれで基板側は問題なかろう
2026-10-11 fabrication toolkitのデータ、よく考えたら使ってないからいらないなと思ったので消去
2026-10-11 JLCPCB製造用データをGit追跡するのはやめだ 自分で生成して、どうぞ(区切りがついたらReleaseに置いておく)
2026-10-11 JLCPCB製造用データの削除
2026-10-11 VSCode設定ファイルの無視をする
2026-10-11 テストファームのビルドに成功、とりあえずコミット
2026-10-11 本番用ファームのビルドをした
2026-10-11 ボードの名前にアンダーバー使っちゃだめらしい 先に言えよ
2026-10-11 本当の本番用ファームこっち(カス)
